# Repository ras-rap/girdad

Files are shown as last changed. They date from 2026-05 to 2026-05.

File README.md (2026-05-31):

# GIrDAd

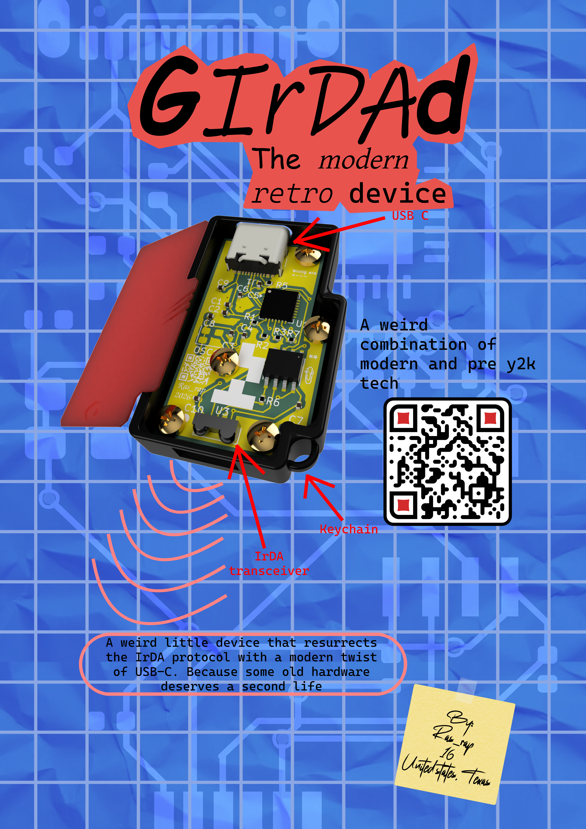
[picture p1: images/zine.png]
Magazine page


A modern USB-C dongle/device for IrDA SIR.

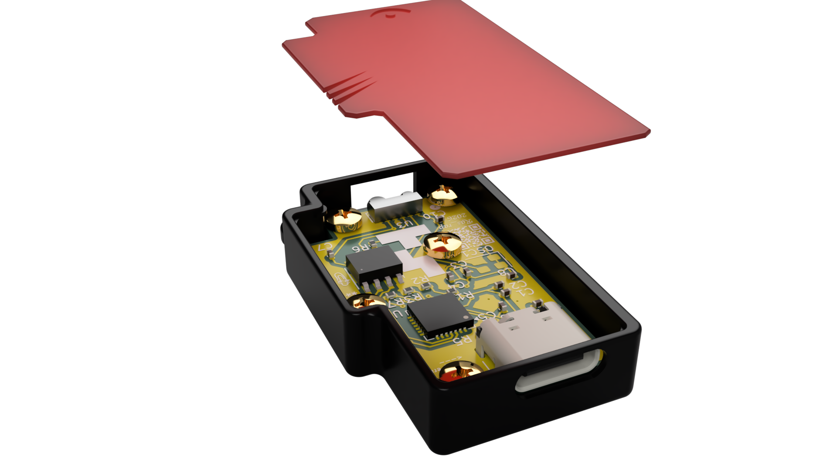
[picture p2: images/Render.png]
Render of GIrDAd

## What is this?
This is a IrDA VCOM device/dongle port thing, it has USB-C on one end, and an IrDA transceiver on the other.

## Why did you make this
I bought a Cipherlab 8001 Mobile Computer at a thrift store, and I want to program it, but I dont want to buy one of the data cradles for it, as they are way too rare and expensive for some pogo pins and an IrDA transceiver, so now we have this, which can be used for much more than the thing I built it for.

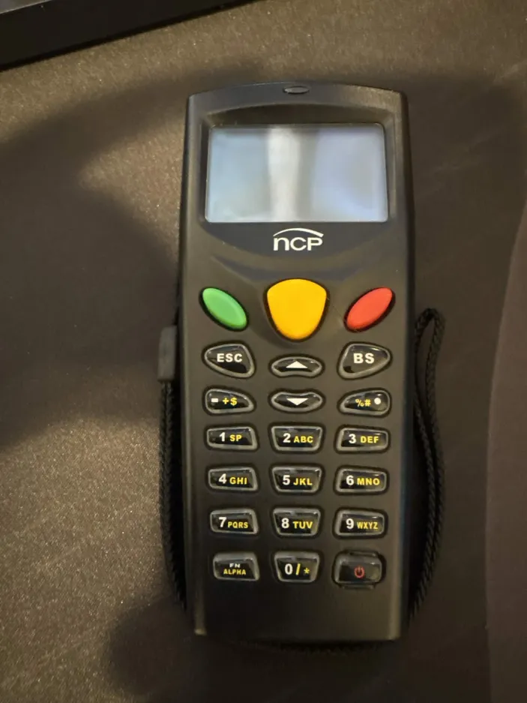
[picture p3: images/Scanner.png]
8001 Mobile Computer


## How do I use it
Well that depends on what you're using it for, but you plug it into your computer, and open up whatever program wants an IrDA SIR port, and use it like you would a device from the late 90's early 2000's

## Specs

- 115.2 kbp/s max transfer rate
- 870-910 nm wavelength
- 1m max usage distance
- 115200 max baud

***Made by Ras_rap for [Hackclub Fallout](https://fallout.hackclub.com/)***

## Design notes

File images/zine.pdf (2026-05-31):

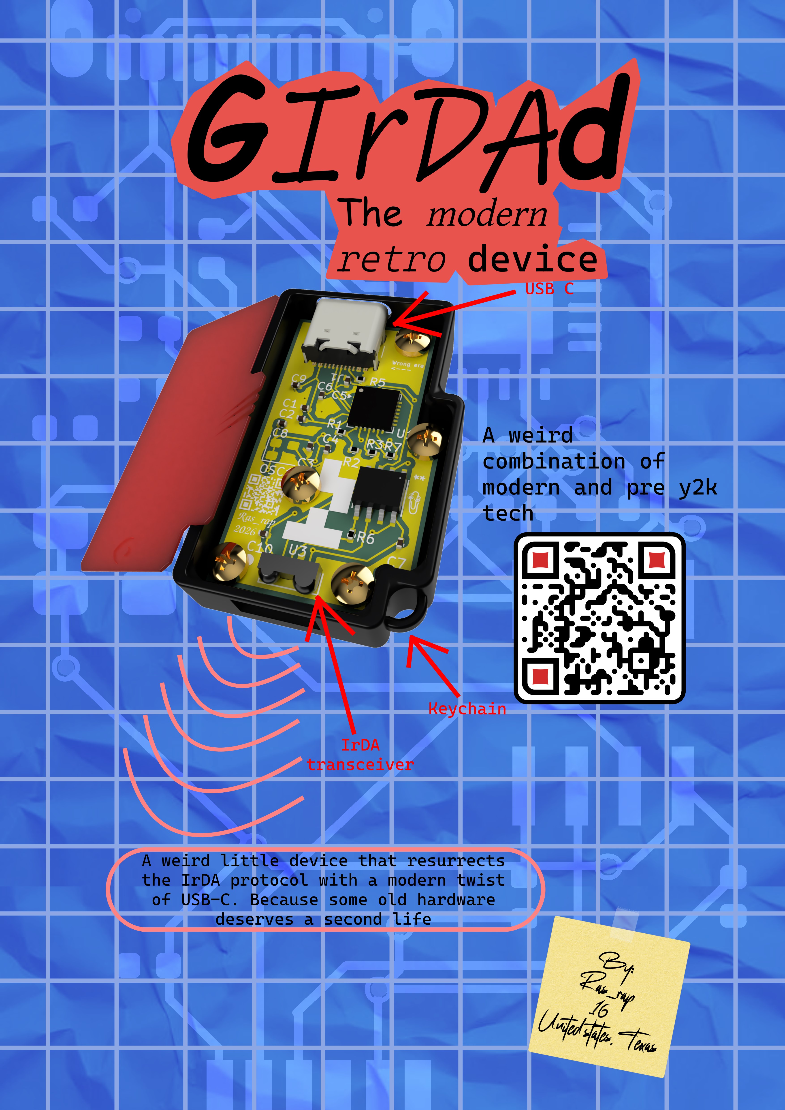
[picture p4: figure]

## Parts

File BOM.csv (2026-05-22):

Reference | Qty | Value | Footprint | Datasheet | Source | Price per unit | Total price
C1,C3,C7,C8,C10 | 5 | 100nF | Capacitor_SMD:C_0402_1005Metric | https://yageogroup.com/content/datasheet/asset/file/KEM_C1002_X7R_SMD | https://www.digikey.com/en/products/detail/kemet/C0402C104K8RACTU/789652 | $0.10 | $0.50
C2 | 1 | 1UF | Capacitor_SMD:C_0402_1005Metric | https://mm.digikey.com/Volume0/opasdata/d220001/medias/docus/609/CL05A105KO5NNNC_Spec_5-2-19.pdf | https://www.digikey.com/en/products/detail/samsung-electro-mechanics/CL05A105KO5NNNC/3886725 | $0.10 | $0.10
C4 | 2 | 4.7Uf | Capacitor_SMD:C_0402_1005Metric | https://mm.digikey.com/Volume0/opasdata/d220001/medias/docus/863/CL05A475MP5NRNC_Spec.pdf | https://www.digikey.com/en/products/detail/samsung-electro-mechanics/CL05A475MP5NRNC/3887140 | $0.10 | $0.20
C5,C6 | 2 | 100pF | Capacitor_SMD:C_0402_1005Metric | https://mm.digikey.com/Volume0/opasdata/d220001/medias/docus/609/CL05C101JB5NNNC_Spec.pdf | https://www.digikey.com/en/products/detail/samsung-electro-mechanics/CL05C101JB5NNNC/3886683 | $0.10 | $0.20
R1 | 1 | 47K OHM | Resistor_SMD:R_0402_1005Metric | https://www.te.com/commerce/DocumentDelivery/DDEController?Action=srchrtrv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 | https://www.digikey.com/en/products/detail/te-connectivity-passive-product/CRGCQ0402F47K/8576249 | $0.10 | $0.10
R2,R3,R4,R7 | 4 | 10K OHM | Resistor_SMD:R_0402_1005Metric | https://yageogroup.com/content/datasheet/asset/file/PYU-RC_GROUP_51_ROHS_L | https://www.digikey.com/en/products/detail/yageo/RC0402JR-0710KL/726418 | $0.10 | $0.40
R5,R6 | 2 | 5.1K OHM | Resistor_SMD:R_0402_1005Metric | https://www.vishay.com/docs/28773/crcwce3.pdf | https://www.digikey.com/en/products/detail/vishay-dale/CRCW04025K10FKEDC/7928491 | $0.10 | $0.20
J1 | 1 | USB_C_Plug_USB2.0 | Connector_USB:USB_C_Receptacle_GCT_USB4105-xx-A_16P_TopMnt_Horizontal | https://gct.co/files/specs/usb4105-spec.pdf | https://www.digikey.com/en/products/detail/gct/usb4105-gf-a/11198441 | $0.80 | $0.80
OSC1 | 1 | ASE-xxxMHz | Oscillator:Oscillator_SMD_Abracon_ASE-4Pin_3.2x2.5mm | https://abracon.com/Oscillators/ASEseries.pdf | https://www.digikey.com/en/products/detail/abracon-llc/ASE-1-8432MHZ-L-C-T/1236871 | $0.98 | $0.98
U1 | 1 | CP2102N-Axx-xQFN28 | Package_DFN_QFN:QFN-28-1EP_5x5mm_P0.5mm_EP3.35x3.35mm | https://www.silabs.com/documents/public/data-sheets/cp2102n-datasheet.pdf | https://www.digikey.com/en/products/detail/silicon-labs/CP2102N-A02-GQFN28/9863477 | $4.67 | $4.67
U2 | 1 | MCP2122-E/SN | MCP2122:SOIC8-N_MC_MCH | https://ww1.microchip.com/downloads/en/DeviceDoc/21894c.pdf | https://www.digikey.com/en/products/detail/microchip-technology/MCP2122-E-SN/704667 | $1.01 | $1.01
U3 | 1 | TFBS4711-TR1 | TFBS4711 (2):CONN6_4711-TR1_VIS | https://www.vishay.com/docs/82633/tfbs4711.pdf | https://www.digikey.com/en/products/detail/vishay-semiconductor-opto-division/TFBS4711-TR3/1681201 | $4.59 | $4.59
 |  |  |  |  |  |  | Total component price
 |  |  |  |  |  |  | $13.75

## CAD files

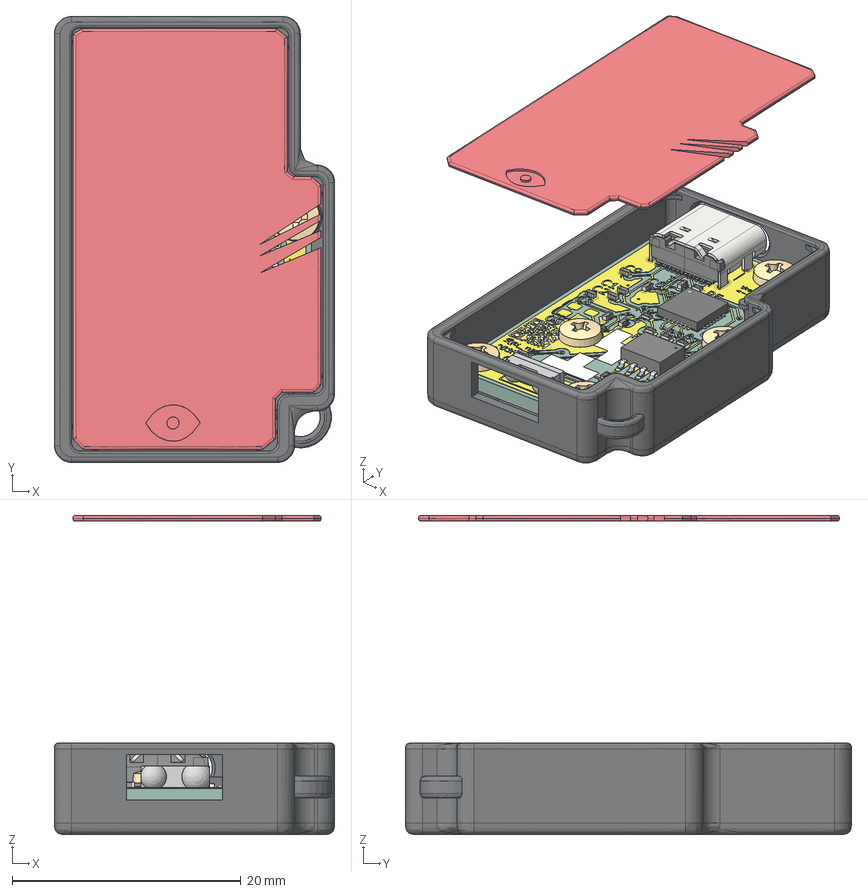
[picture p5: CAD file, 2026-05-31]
models/Full-model.step
24.5 x 39.0 x 27.9 mm
BHS JIS B 1111 - M2x4 Brass Plain x 5

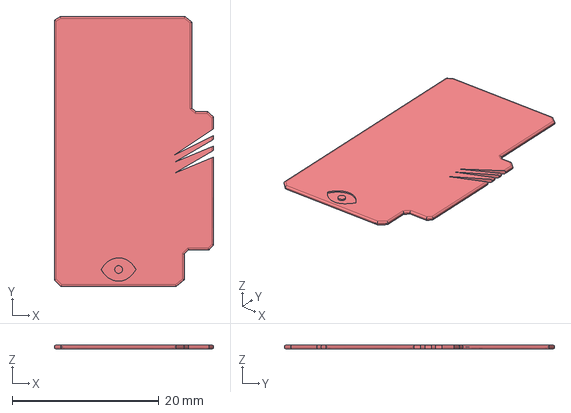
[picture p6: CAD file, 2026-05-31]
models/Case-top.step
21.7 x 36.8 x 0.5 mm

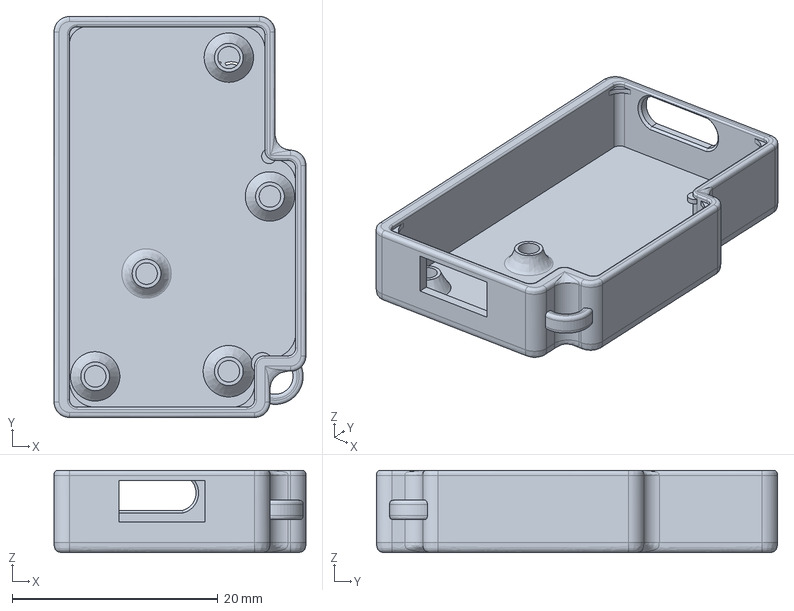
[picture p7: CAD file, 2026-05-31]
models/Case-bottom.step
24.5 x 39.0 x 8.00 mm

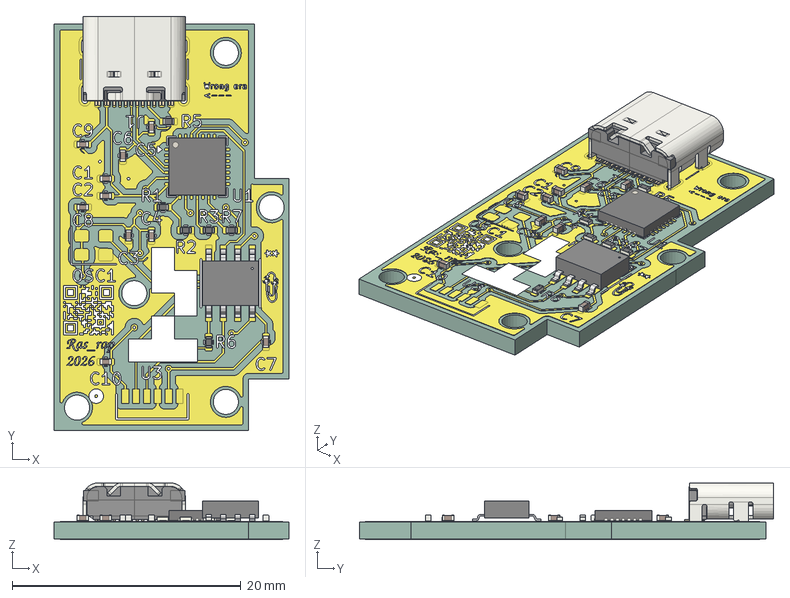
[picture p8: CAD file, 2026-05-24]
models/board.step
20.5 x 36.2 x 4.98 mm
C_0402_1005Metric x 10
R_0402_1005Metric x 6
USB_C_Receptacle_16P_TopMnt_Horizontal_GCT_USB4105-xx-A
QFN-28-1EP_5x5mm_Pitch0.5mm
girdad_copper
girdad_silkscreen x 2
girdad_PCB

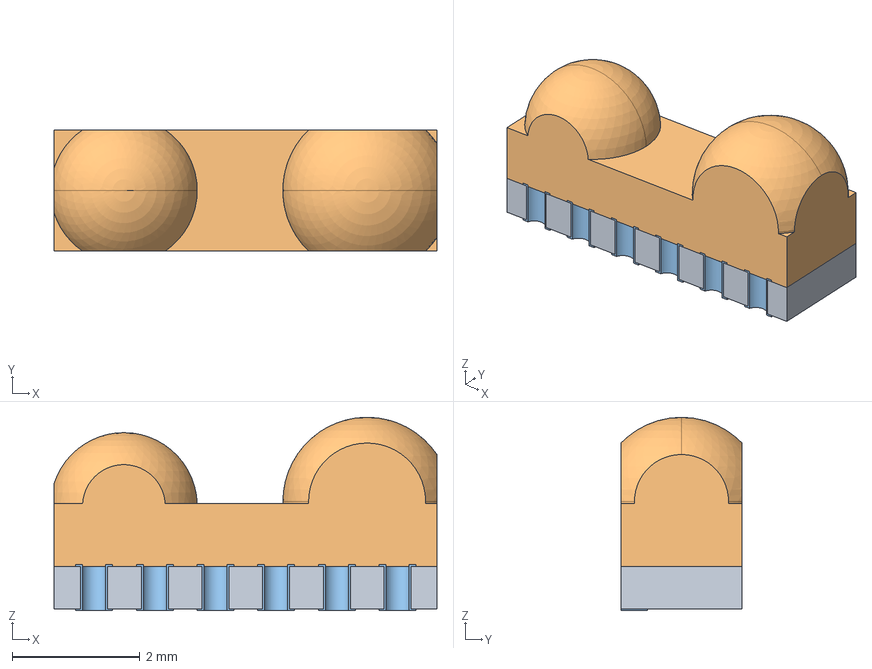
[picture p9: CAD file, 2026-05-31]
models/84406TFBS4711.stp
6.00 x 1.90 x 3.03 mm
PLATINE
GEHAEUSE
KONTAKT x 6

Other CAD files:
models/Case-bottom.f3d
models/Case-top.f3d

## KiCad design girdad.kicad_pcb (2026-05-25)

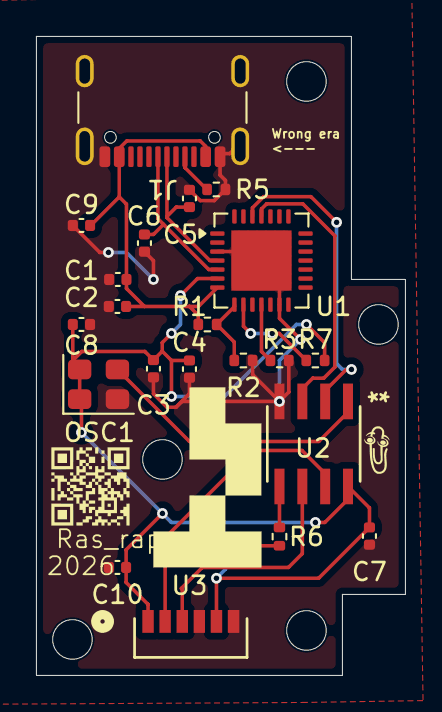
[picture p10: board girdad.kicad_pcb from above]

Board: 2 copper layers, 20.5 x 35.5 mm, 21 parts (0 on the bottom side), 15 nets.

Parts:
C1, C2, C3, C4, C5, C6, C7, C8, C9, C10: C_Small_US; C_0402_1005Metric
J1: USB_C_Plug_USB2.0; USB_C_Receptacle_GCT_USB4105-xx-A_16P_TopMnt_Horizontal
OSC1: ASE-xxxMHz; Oscillator_SMD_Abracon_ASE-4Pin_3.2x2.5mm
R1, R2, R3, R5, R6, R7: R; R_0402_1005Metric
U1: CP2102N-Axx-xQFN28; QFN-28-1EP_5x5mm_P0.5mm_EP3.35x3.35mm
U2: MCP2122-E/SN; SOIC8-N_MC_MCH
U3: TFBS4711-TR1; CONN6_4711-TR1_VIS

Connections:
/3.3V: C3.2, C4.2, C7.2, C8.2, C10.2, OSC1.1 (EN), OSC1.4 (Vdd), R6.1, R7.2, U1.6 (VDD), U2.8 (VDD), U3.1, U3.5
/GND: C1.2, C2.2, C3.1, C4.1, C5.1, C6.2, C7.1, C8.1, C9.1, C10.1, J1.A1 (GND), J1.A12 (GND), J1.B1 (GND), J1.B12 (GND), J1.SH (SHIELD), OSC1.2 (GND), R2.2, R3.2, R5.1, U1.3 (GND), U1.13 (CHREN), U1.29 (GND), U2.4 (VSS), U3.4, U3.6
unnamed: J1.A5 (CC), R5.2
unnamed: C5.2, J1.A6 (D+), U1.4 (D+)
unnamed: C6.1, J1.A7 (D-), U1.5 (D-)
unnamed: OSC1.3 (OUT), U2.1 (16XCLK)
unnamed: U1.25 (RXD), U2.3 (RX)
unnamed: U1.26 (TXD), U2.2 (TX)
unnamed: R1.1, R2.1, U1.8 (VBUS)
unnamed: C1.1, C2.1, C9.2, J1.A4 (VBUS), J1.A9 (VBUS), J1.B4 (VBUS), J1.B9 (VBUS), R1.2, U1.7 (VREGIN)
unnamed: R7.1, U1.9 (~RST)
unnamed: R3.1, U1.11 (~SUSPEND)
unnamed: R6.2, U2.5 (RESET)
unnamed: U2.6 (RXIR), U3.3
unnamed: U2.7 (TXIR), U3.2

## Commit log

2026-05-17 Commit all files
    [.kicad_sch, .kicad_sch.kicad_sch, girdad.kicad_sch]
2026-05-22 Made the PCB, and the BOM, now to 3d model a case for it
    [BOM.csv, girdad.kicad_pcb, girdad.kicad_sch]
2026-05-23 Add mounting holes and silkscreen images and messages (More to come)
    [.kicad_sch.kicad_sch, girdad.kicad_pcb, girdad.kicad_sch]
2026-05-24 Enough silkscreen
    [girdad.kicad_pcb]
2026-05-24 I need to use fusion, not onshape
    [84406TFBS4711.stp, board.step]
2026-05-25 Fixed a silkscreen thing
    [girdad.kicad_pcb]
2026-05-31 README and zine page
    [84406TFBS4711.stp, Case-bottom.step, Case-top.step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]
2026-05-31 Add f3d files, remove 3d folder
    [84406TFBS4711.stp, Case-bottom.f3d, Case-top.f3d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]
2026-05-31 Remove locks and backups
    [.kicad_sch, .kicad_sch.kicad_sch, girdad.kicad_pcb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]
